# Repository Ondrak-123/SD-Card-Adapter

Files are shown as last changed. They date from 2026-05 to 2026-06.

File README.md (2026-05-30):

# SD Card Adapter
---
## Introduction
**- This is an SD + micro SD card to USB A adapter, that supports USB 2.0.**
#### **Parts, usage, description:**
- The main chip for this project will be GL823K from Genesys Logic, that supports USB 2.0 (High-Speed 480 Mbps), this chip is great thanks to its simplicity since it has integrated 5V to 3V3, 3V3 to 1V8 regulators and it also has a crystal integrated so no external crystal or timing capacitors needed. (The datasheet for this can be found at alldatasheet.com.
- LED included to show its status.
- All of the data lines D0-D3 and CMD needs to have pull ups (10K to 3V3), (excluding CLK).
- Decoupling capacitors 100nF for each power pin on the IC (VDD, VDDA).
- Mosfet for powering the SD cards.
- A protection circuit that cuts off power to the other SD card if both are plugged in.
- 4 Layer Board, (Each layer having a ground pour). First layer (Top): Signals, Data lines, Second layer (Inner1): pure ground, no normal traces, Third layer (Inner2): power, 5V, 3,3V and nets like SDPWR, BIGSDPWR, Fourth layer (Bottom): signal traces that did not fit on the first layer, and everything else that didnt fit on top.
- Each data line (D+, D-) should have impedance of around 90R, also the traces should be the same width, lenght and spacing.

## Schematic:


## PCB:
Snímek obrazovky 2026-05-27 183753
Snímek obrazovky 2026-05-27 183741
Snímek obrazovky 2026-05-27 183728
Snímek obrazovky 2026-05-27 183711

## 3D Rendering:
Snímek obrazovky 2026-05-28 173509
Snímek obrazovky 2026-05-28 173557
Snímek obrazovky 2026-05-28 180752

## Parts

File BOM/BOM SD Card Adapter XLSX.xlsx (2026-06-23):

No. | Quantity | Comment | Designator | Footprint | Value | Manufacturer Part | Manufacturer | Supplier Part | Supplier | Total price (USD) $
1 | 1 | 4.7uF | C1 | Capacitor_SMD:C_0603_1608Metric | 4.7uF |  |  | C69335 | LCSC | 0.49
2 | 1 | 10uF | C2 | Capacitor_SMD:C_0603_1608Metric | 10uF |  |  | C962136 | LCSC | 0.43
3 | 2 | 100nF | C3,C4 | Capacitor_SMD:C_0603_1608Metric | 100nF | CL10B104KO8NNNC | SAMSUNG(三星) | C66501 | LCSC | 0.73
4 | 1 | XKSD-013 | CARD1 | SIM-SMD_XKSD-013 |  | XKSD-013 | XKB Connection(中国星坤) | C2764609 | LCSC | 0.83
5 | 1 | TF PUSH | CARD2 | TF-SMD_TF-PUSH |  | TF PUSH | SHOU HAN(首韩) | C393941 | LCSC | 0.65
6 | 1 | YLED0603B | D1 | LED_SMD:LED_0603_1608Metric |  | YLED0603B | YONGYUTAI(永裕泰) | C19171394 | LCSC | 0.61
7 | 1 | MPZ2012S601AT000 | L1 | Inductor_SMD:L_0805_2012Metric |  | MPZ2012S601AT000 | TDK | C21519 | LCSC | 0.26
8 | 2 | AO3401A | Q1,Q3 | Package_TO_SOT_SMD:SOT-23 |  | AO3401A | baocheng(宝乘) | C48678024 | LCSC | 0.62
9 | 1 | 2N7002 | Q2 | Package_TO_SOT_SMD:SOT-23 |  | 2N7002 | JSMSEMI(杰盛微) | C916396 | LCSC | 0.44
10 | 2 | 27Ω | R1,R2 | Resistor_SMD:R_0603_1608Metric | 27Ω | RC0603FR-0727RL | YAGEO(国巨) | C137753 | LCSC | 0.2
11 | 8 | 10kΩ | R3,R4,R5,R6,R7,R8,R9,R10 | Resistor_SMD:R_0603_1608Metric | 10kΩ | FRC0603J103 TS | FOJAN(富捷) | C2930027 | LCSC | 0.13
12 | 1 | 470Ω | R11 | Resistor_SMD:R_0603_1608Metric | 470Ω | FRC0603J471 TS | FOJAN(富捷) | C2907172 | LCSC | 0.18
13 | 1 | GL823K-HCY04 | U2 | SSOP-16_L4.9-W3.9-P0.64-LS6.0-BL |  | GL823K-HCY04 | GENESYS(创惟) | C284879 | LCSC | 0.46
14 | 1 | USB-212-BCW | USB1 | USB-A-SMD_USB-212-BCW |  | USB-212-BCW | XUNPU(讯普) | C720521 | LCSC | 0.54
15 | 1 | PCB |  |  |  |  | JLPCB |  |  | 4.24
16 |  | LCSC Shipping |  |  |  |  | LCSC |  |  | 10.35
 |  | LCSC Handling fee |  |  |  |  |  |  |  | 3
 |  |  |  |  |  |  |  |  |  | 24.16
 |  |  |  |  |  |  |  |  | Total: | 25 $ USD
 |  |  |  |  |  |  |  |  |  | ’+28$ EU CFF
 |  |  |  |  |  |  |  |  | Requesting amount: | 55$
 |  |  |  |  | The whole LCSC cart can be downloaded on the Github. (So you can see and add all the items).
 |  |  |  |  | Since 1. July 2026 there will be a new Category Flat Fee, affecting all EU residents, for each category (HS Code) of items there will be a flat
 |  |  |  |  | fee of 3€, the HS Codes for this package are: HS853224, HS853321, HS853400, HS853669, HS850450, HS854121, HS854141, and HS854231.
 |  |  |  |  | Which is 8*3€ or 24€ (28$). This fee will be added automatically when
 |  |  |  |  | checking out (starting on 1.7.2026). But if I order a package on the 20.6. and the package will arrive to the borders in July I will
 |  |  |  |  | still need to pay the fees. THIS IS NOT A LOCAL/POST OR A COUNTRY FEE!!!

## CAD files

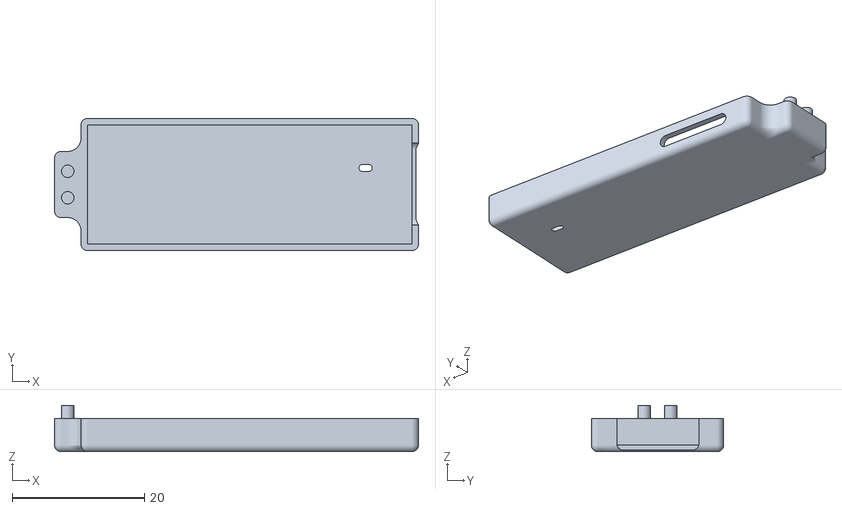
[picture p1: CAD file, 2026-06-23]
Fusion files + STLs/SD CARD ADAPTER Top.stl
55.0 x 20.0 x 7.00

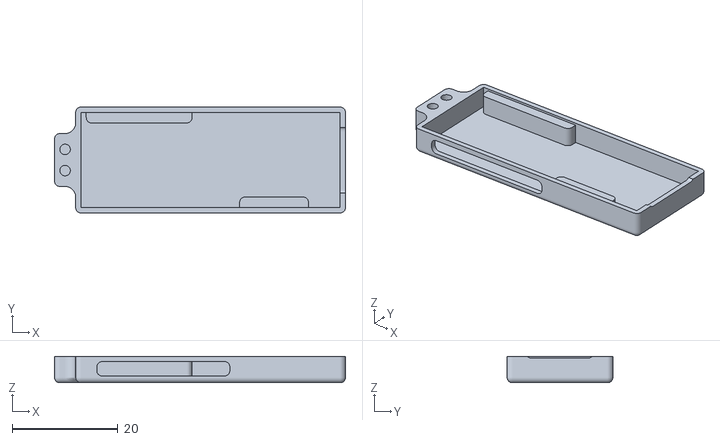
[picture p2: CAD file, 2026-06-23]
Fusion files + STLs/SD CARD ADAPTER BOTTOM.stl
55.0 x 20.0 x 5.00

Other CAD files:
Fusion files + STLs/SD CARD ADAPTER, ALL.f3d

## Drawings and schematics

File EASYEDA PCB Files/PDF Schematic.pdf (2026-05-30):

## USB A

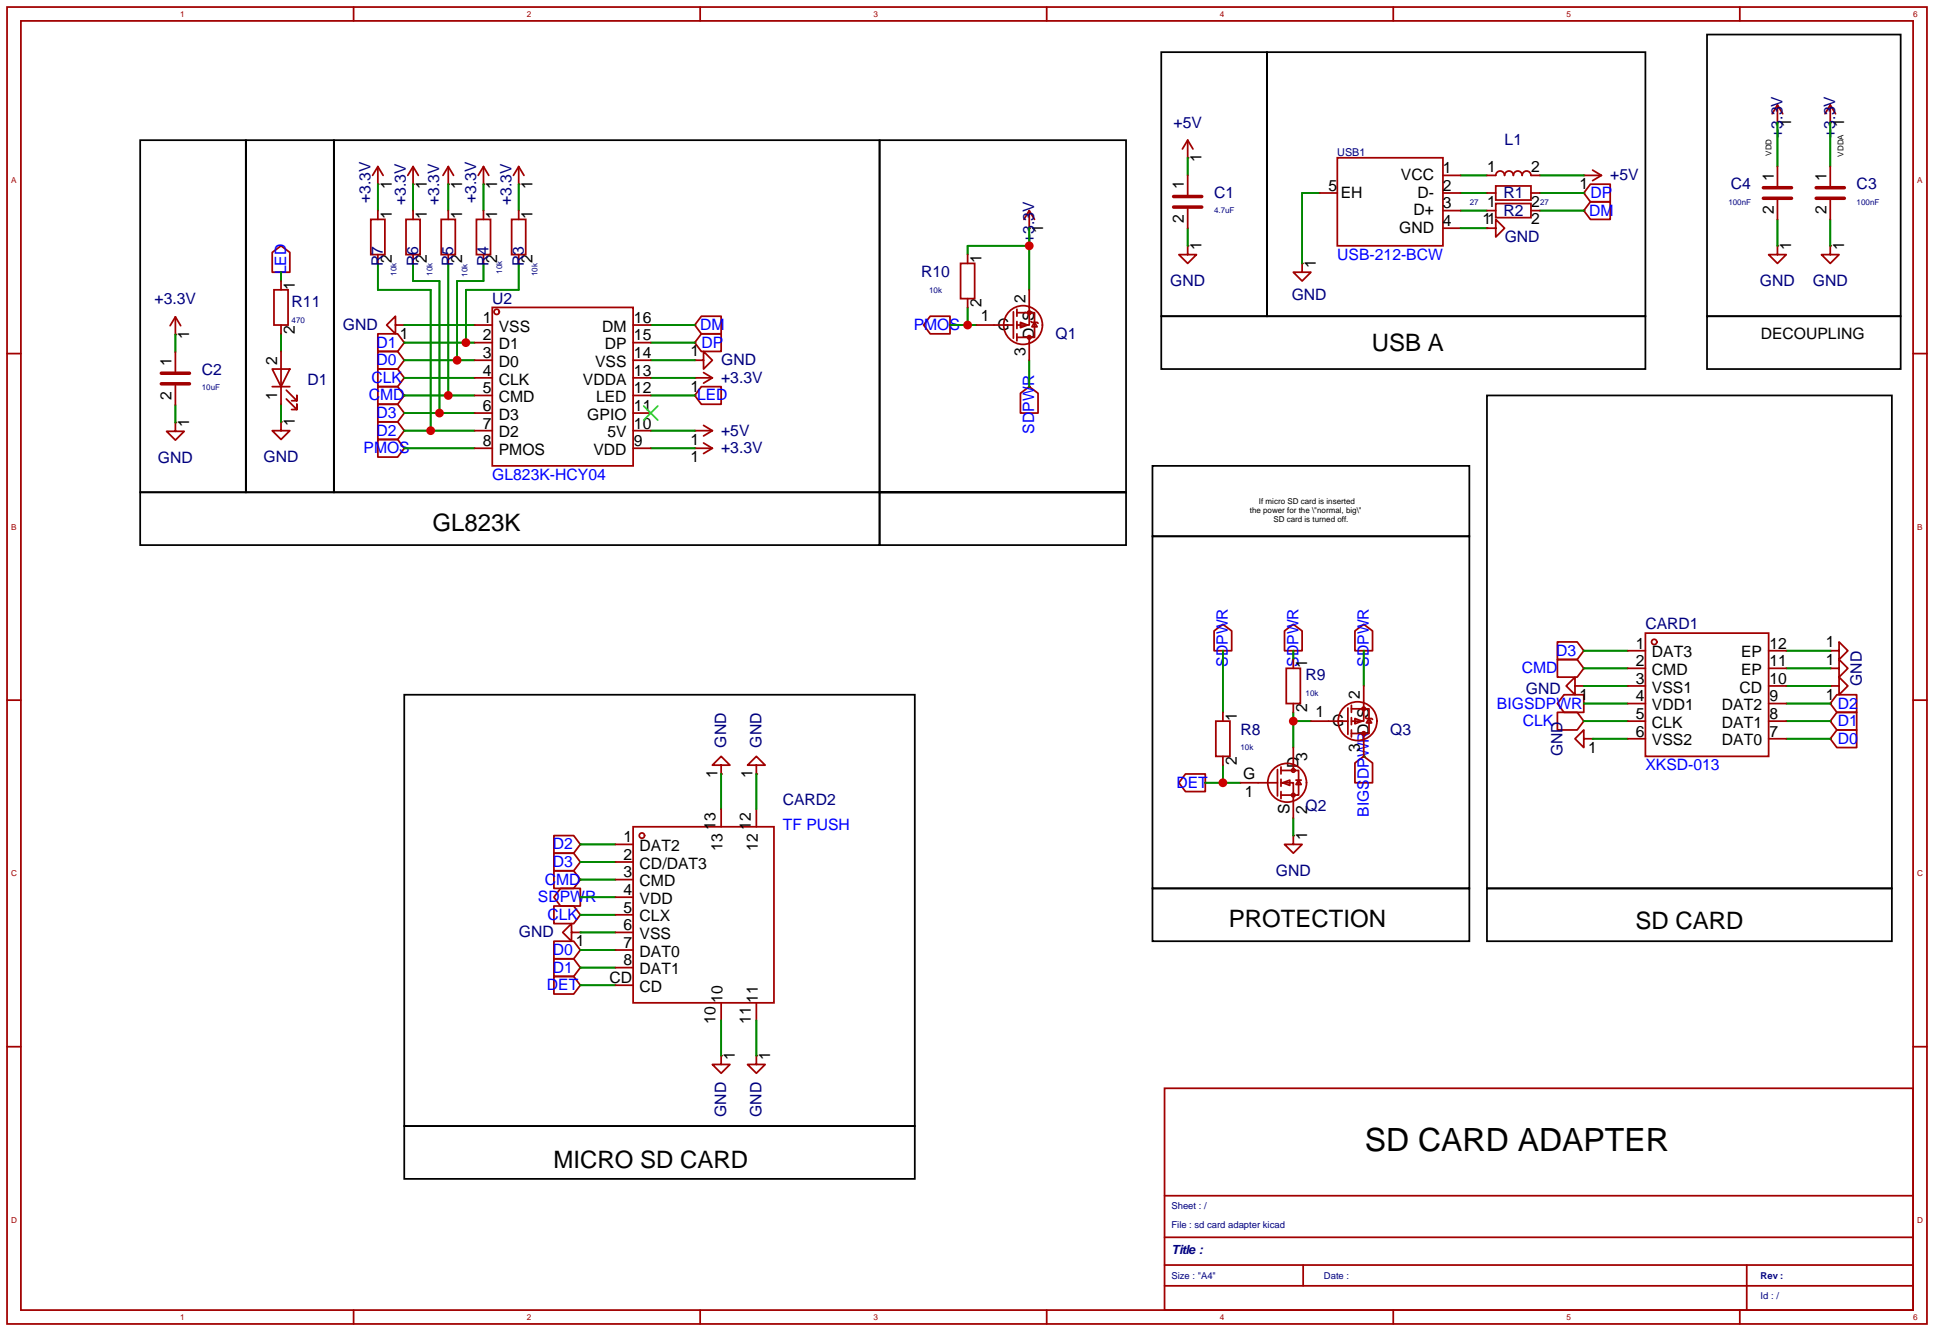
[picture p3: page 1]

5V 10 GPIO 11 LED 12 VDDA 13 VSS 14 DP 15 DM 16

If micro SD card is inserted
the power for the \"normal, big\"
SD card is turned off.

Sheet : /
File : sd card adapter kicad
Title :

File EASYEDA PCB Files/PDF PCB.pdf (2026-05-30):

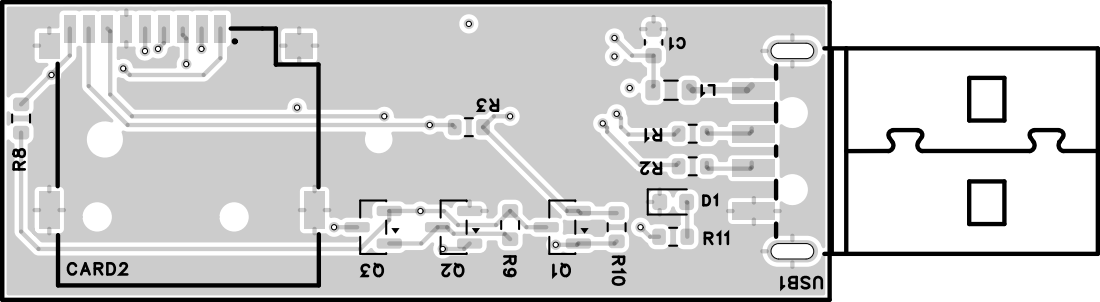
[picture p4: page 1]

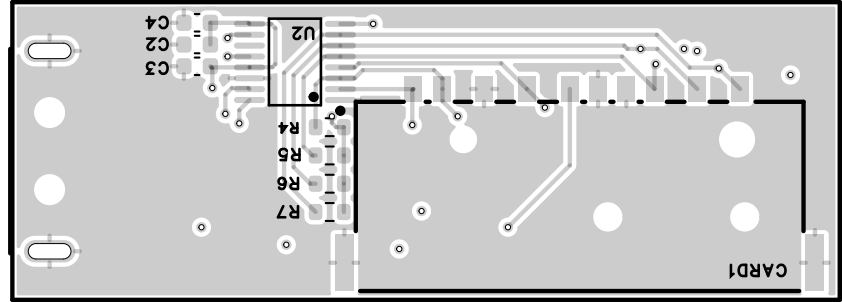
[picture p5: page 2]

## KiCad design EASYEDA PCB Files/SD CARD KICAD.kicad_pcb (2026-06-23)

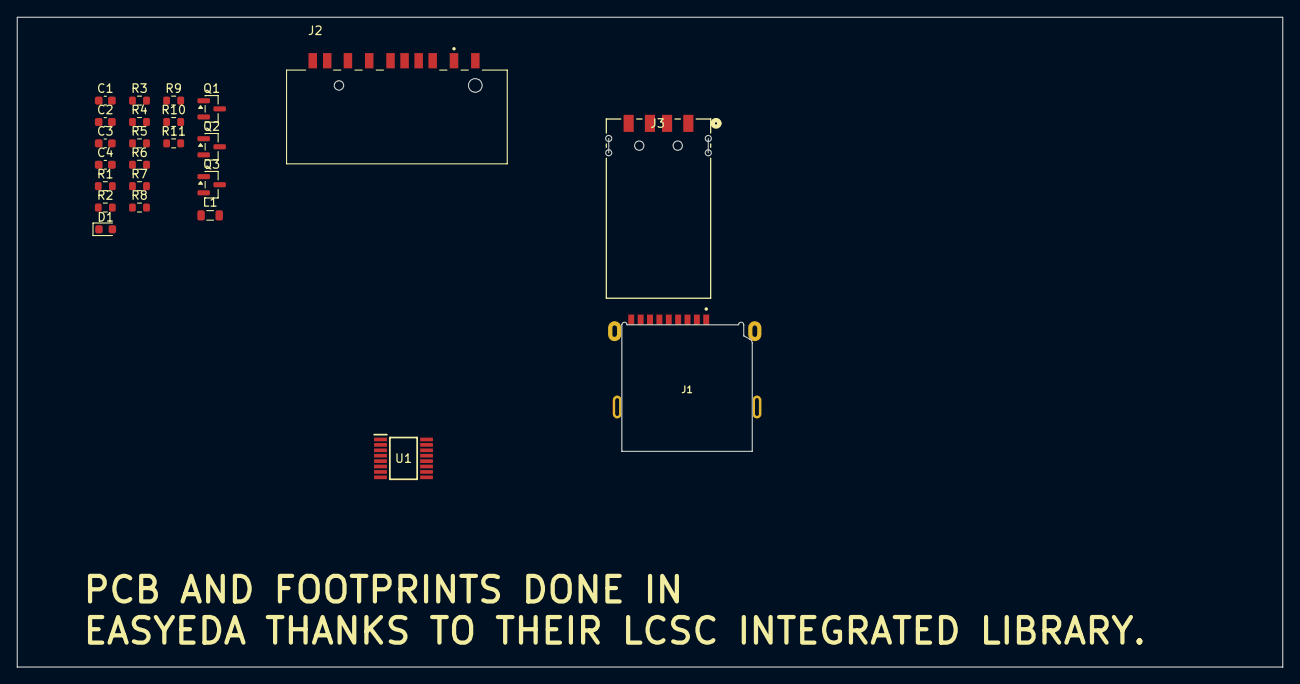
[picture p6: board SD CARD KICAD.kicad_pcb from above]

Board: 2 copper layers, 148.5 x 76.2 mm, 24 parts (0 on the bottom side), 21 nets, no tracks yet.

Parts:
C1: 4.7uF; C_0603_1608Metric
C2: 10uF; C_0603_1608Metric
C3, C4: 100nF; C_0603_1608Metric
D1: LED; LED_0603_1608Metric
J1: Micro_SD_Card_Det1; CUI_MSD-3-A
J2: SD_Card_Receptacle; CUI_SD-6-B
J3: USB_A; CONN_48037-2100_MOL
L1: 600R 100MHz; L_0805_2012Metric
Q1, Q3: AO3401A; SOT-23
Q2: 2N7002; SOT-23
R1, R2: 27R; R_0603_1608Metric
R3, R4, R5, R6, R7, R8, R9, R10: 10K; R_0603_1608Metric
R11: 470R; R_0603_1608Metric
U1: GL823K-HCY04; SOP64P600X175-16N

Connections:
+3.3V: C2.1, C3.1, C4.1, Q1.2 (S), R3.1, R4.1, R5.1, R6.1, R7.1, R10.1, U1.9 (VDD), U1.13 (VDDA)
+5V: C1.1, L1.2, U1.10 (5V)
BIGSDPWR: J2.4 (VDD), Q3.3 (D)
CLK: J1.5 (CLK), J2.5 (CLK), U1.4 (CLK)
CMD: J1.3 (CMD), J2.2 (CMD), R5.2, U1.5 (CMD)
D0: J1.7 (DAT0), J2.7 (DAT0), R4.2, U1.3 (D0)
D1: J1.8 (DAT1), J2.8 (DAT1), R3.2, U1.2 (D1)
D2: J1.1 (DAT2), J2.9 (DAT2), R7.2, U1.7 (D2)
D3: J1.2 (DAT3/CD), J2.1 (CD/DAT3), R6.2, U1.6 (D3)
DET: Q2.1 (G), R8.2
DM: R2.2, U1.16 (DM)
DP: R1.2, U1.15 (DP)
GND: C1.2, C2.2, C3.2, C4.2, D1.1 (K), J1.6 (VSS), J2.3 (VSS), J2.6 (VSS), J2.CD, J3.4 (GND), Q2.2 (S), U1.1 (VSS), U1.14 (VSS)
LED: R11.1, U1.12 (LED)
unnamed: D1.2 (A), R11.2
unnamed: J3.3 (D+), R1.1
unnamed: J3.2 (D-), R2.1
unnamed: J3.1 (VBUS), L1.1
unnamed: Q2.3 (D), Q3.1 (G), R9.2
PMOS: Q1.1 (G), R10.2, U1.8 (PMOS)
SDPWR: J1.4 (VDD), Q1.3 (D), Q3.2 (S), R8.1, R9.1
